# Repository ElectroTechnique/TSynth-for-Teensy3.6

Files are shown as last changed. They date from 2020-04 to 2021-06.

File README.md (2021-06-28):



# Teensy 3.6 based synthesizer using PJRC Audio Board and Audio Lib

# Superceded by Teensy 4.1 version

Website: [electrotechnique.cc](https://electrotechnique.cc)

The pcb and front panel to build TSynth will be available around May 2020 from [Tindie](https://www.tindie.com/products/electrotechnique/tsynth-teensy-based-diy-programmable-poly-synth/) with SMD 4067 multiplexers, 6N138 opto-isolator, capacitors and resistors fitted. The entire cost of parts to build TSynth will be around $99 if you buy components from the cheaper suppliers and the build time around two hours to solder. Plans for a 3D printed/laser cut enclosure will be available.
Questions: info@electrotechnique.cc

# Instructions

The source code requires Teensyduino from [PJRC](https://pjrc.com) to compile. You also need CircularBuffer from Agileware and Adafruit_GFX, which are available in the Arduino Library Manager. The latest TeensyDuino v1.54beta9+ appears to work fine now.

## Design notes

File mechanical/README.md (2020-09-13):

- Electrical schematic
- 3D models
- Laser cutter plans
- Mechanical plans
- BOM Excel file for ordering from Mouser

- T4.1 to T3.6 Adapter Board KiCAD files and gerbers for JLCPCB. Use to fit a T4.1 on the Rev 1.1 T3.6-based board. You do not need this unless you want to covert your Rev1.1 PCB to use a T4.1 and use the firmware.

Fusion 360 models. These have internal dimensions for slots that are slightly bigger, to account for shrinkage of PLA plastic:
- [End Cheeks](https://a360.co/3azEESA)
- [Side Panel Column](https://a360.co/34T8akU)

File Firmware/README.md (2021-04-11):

This is the current firmware for TSynth - use the latest, earlier ones will be left here. It is a hex file that is flashed to Teensy using [Teensy Loader from PJRC](https://www.pjrc.com/teensy/loader.html) You will probably need to press the button on a the Teensy for the firmware to flash.

- V1.29 - Stereo chorus improvement.

- V1.28 - Mod wheel level adds to osc LFO level.

- V1.27 - The volume control affects digital and analogue audio together. This can be loud on the headphone socket.

- V1.26 - Improve ADC reads to decrease noise and increase sensitivity to pot changes. Increase AudioMemory to 48.

- V1.24 - Improved filter response at higher frequencies.

- V1.23 - Added MIDI Out - panel controls will send MIDI CC data over a channel set in Settings through USB Host and Client MIDI ports. Added VU Meter that shows peak amplitude on display (enabled in Settings.) Not a true VU meter, however.

- V1.22 - Fixed glide behaviour when notes were held.

- V1.21 - Fixed odd glide behaviour. Now glides correctly from previous note.

- V1.20 - Added oscilloscope display option in Settings. This is an 'experimental feature' that needs more work.

- V1.19 - Added 'Pick-up' option which allows certain controls (both front panel and MIDI) to only change the value when the current patch value is 'picked-up'. For example, if Freq Cutoff is set to 312Hz, adjusting Filter Cutoff will pick-up the value when the control is near 312Hz and then change it. This prevents sudden jumps in sound when playing and adjusting. Filter Cuttoff, Resonance, Filter Type, Pitch LFO Amount, Pitch LFO Rate, Filter LFO Amount, Filter LFO Rate, FX Amount and FX Mix have pick-up as these are most likely to be adjusted during performance. This feature is somewhat experimental but good enough to include. An indicator, 'PK' shows when pick-up is enabled on the parameter value page of the display. Also added 'Bass Enhance' to the Settings menu. This enhances bass frequencies using the SGTL5000 audio codec chip (not the Teensy) and will only be heard through the headphone jack not USB digital audio.

- V1.17 - Velocity sensitivity added. There are four velocity curves (see [electrotechnique.cc](https://electrotechnique.cc) post about this) that change the volume level with the velocity value. Also a minor fix to PWM source changing that failed to switch the filter envelope on when coming from fixed PW.

- V1.16 - Envelopes closed when a patch changes or the Panic button is pressed, to prevent next patch sounding.

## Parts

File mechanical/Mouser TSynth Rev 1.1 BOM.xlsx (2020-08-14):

Mouser # | Mfr. # | Manufacturer | Description | Order Qty. | Datasheet URL | Quoted Part Number | Order Quantity | Order Price | Min\Mult Order Qty
474-DEV-14057 | DEV-14057 | SparkFun Electronics | Development Boards & Kits - ARM Teensy 3.6 | 1 |  | 474-DEV-14057 | 1 | $32.50 | 1\1
474-DEV-15421 | DEV-15421 | SparkFun Electronics | Audio IC Development Tools Teensy Audio Adaptor Board | 1 |  | 474-DEV-15421 | 1 | $17.50 | 1\1
652-PTV09A-4025UB103 | PTV09A-4025U-B103 | Bourns | Potentiometers 10K LINEAR 20% | 33 | https://www.mouser.com/datasheet/2/54/ptv09-777818.pdf | 652-PTV09A-4025UB103 | 33 | $0.672 | 1\1
653-B3F-4055 | B3F-4055 | Omron | Tactile Switches 12x12mm Std Ht .3 High-force 260g | 7 | https://www.mouser.com/datasheet/2/307/en-b3f-13826.pdf | 653-B3F-4055 | 7 | $0.44 | 1\1
642-AKTS22K | AKTSC22K | Apem | Switch Bezels / Switch Caps ROUND BLACK CAP | 7 | https://www.mouser.com/catalog/additional/Apem_6420_RoHS_Certificate.pdf | 642-AKTS22K | 7 | $0.23 | 1\1
859-LTL-4251NLC | LTL-4251NLC | Lite-On | Standard LEDs - Through Hole Yellow | 4 | https://www.mouser.com/catalog/additional/Lite_On_5938_RoHS_Certificate.pdf | 859-LTL-4251NLC | 4 | $0.14 | 1\1
652-PEC11R-4215K-S24 | PEC11R-4215K-S0024 | Bourns | Encoders 15mm SHAFT w/SWITCH | 1 | https://www.mouser.com/datasheet/2/54/PEC11R-777457.pdf | 652-PEC11R-4215K-S24 | 1 | $1.63 | 1\1
530-SS-52100-001 | SS-52100-001 | Bel | USB Connectors USB 2.0 R Angle Recpt Type A solder | 1 | https://belfuse.com/resources/datasheets/stewartconnector/ds-stw-usb-2.0-and-3.0-connectors.pdf | 530-SS-52100-001 | 1 | $0.43 | 1\1
530-SS-52300-001 | SS-52300-001 | Bel | USB Connectors USB 2.0 RA Receptacle Type B | 1 | https://belfuse.com/resources/datasheets/stewartconnector/ds-stw-usb-2.0-type-b-connectors.pdf | 530-SS-52300-001 | 1 | $0.98 | 1\1
161-3507-E | 161-3507-E | Kobiconn | Phone Connectors PHONE 3.5MM STEREO | 1 | https://www.mouser.com/datasheet/2/209/KC-301159-1171664.pdf | 161-3507-E | 1 | $0.96 | 1\1
806-KCDX-5S-N | KCDX-5S-N | Kycon | Circular DIN Connectors 5P R/A PCB NON SHLD 10mm CIRC DIN RECPT | 1 | https://www.mouser.com/datasheet/2/222/KCDX-334811.pdf | 806-KCDX-5S-N | 1 | $0.86 | 1\1

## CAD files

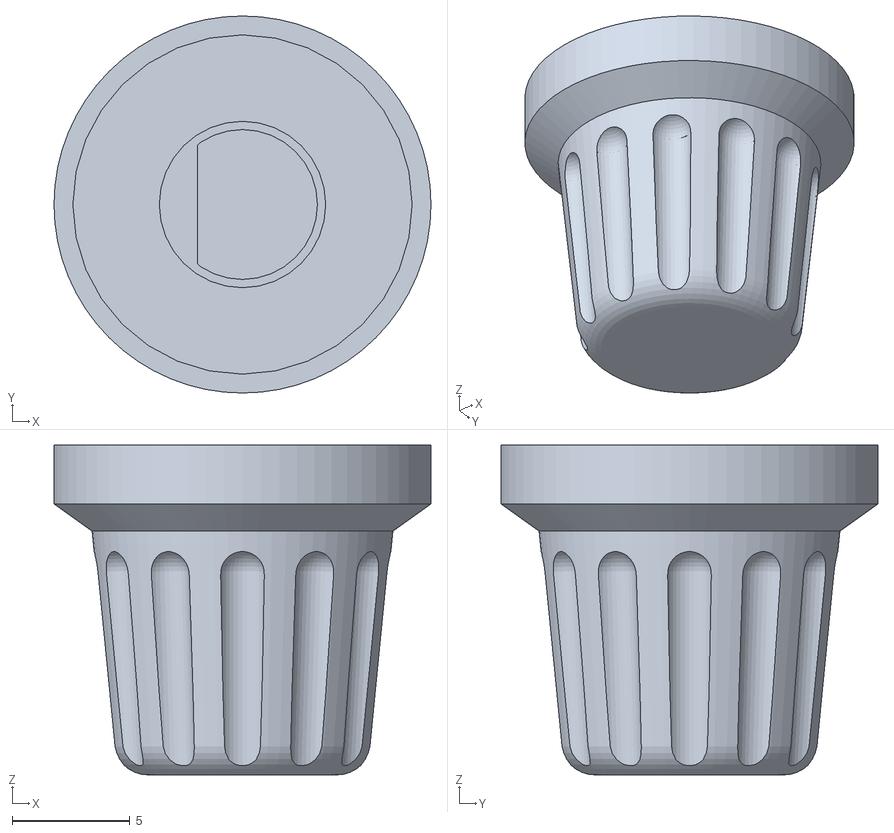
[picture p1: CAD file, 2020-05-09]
mechanical/EncoderKnobEC12.stl
16.0 x 16.0 x 14.0

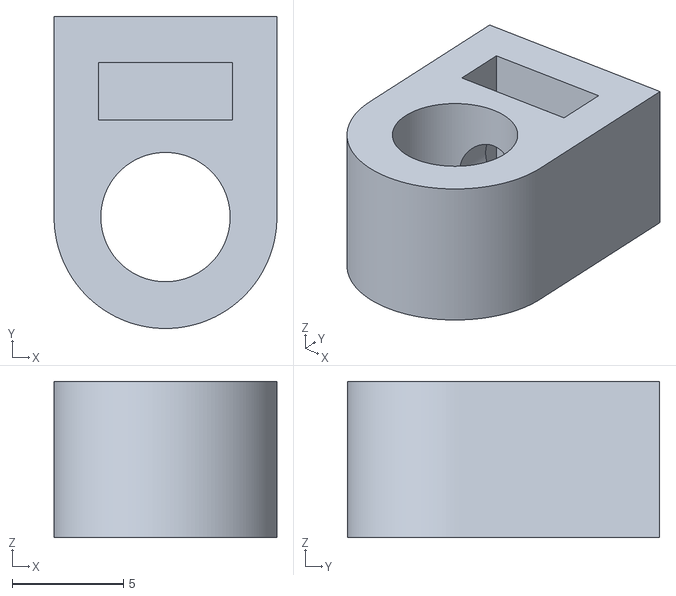
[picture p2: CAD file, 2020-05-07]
mechanical/Side_Panel_Column.stl
10.0 x 14.0 x 7.00

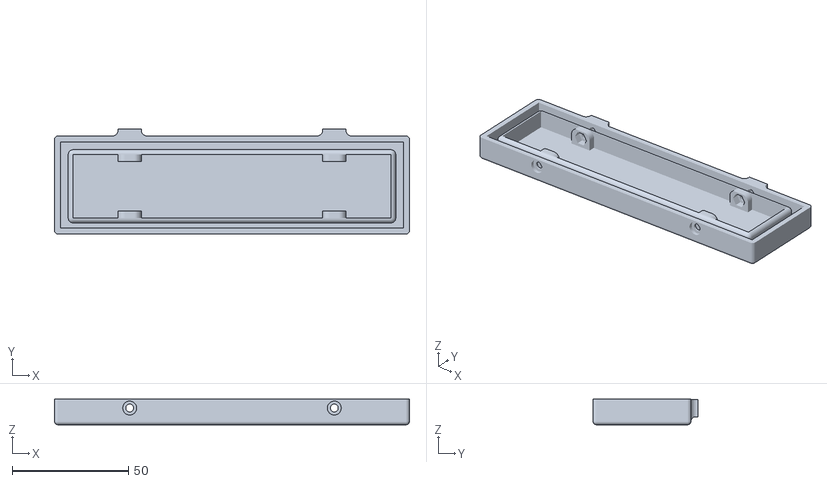
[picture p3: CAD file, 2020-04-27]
mechanical/EndCheek.stl
152.5 x 45.1 x 11.0

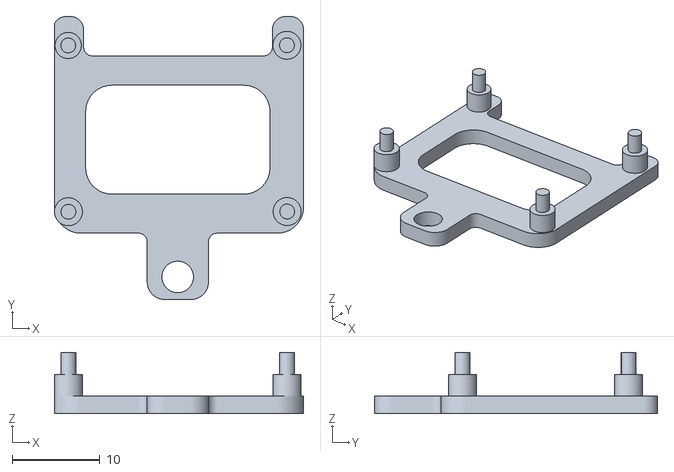
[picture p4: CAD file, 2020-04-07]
mechanical/0_96_Display_Standoff.stl
28.5 x 32.3 x 7.00

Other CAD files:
mechanical/EncoderKnobEC12.scad

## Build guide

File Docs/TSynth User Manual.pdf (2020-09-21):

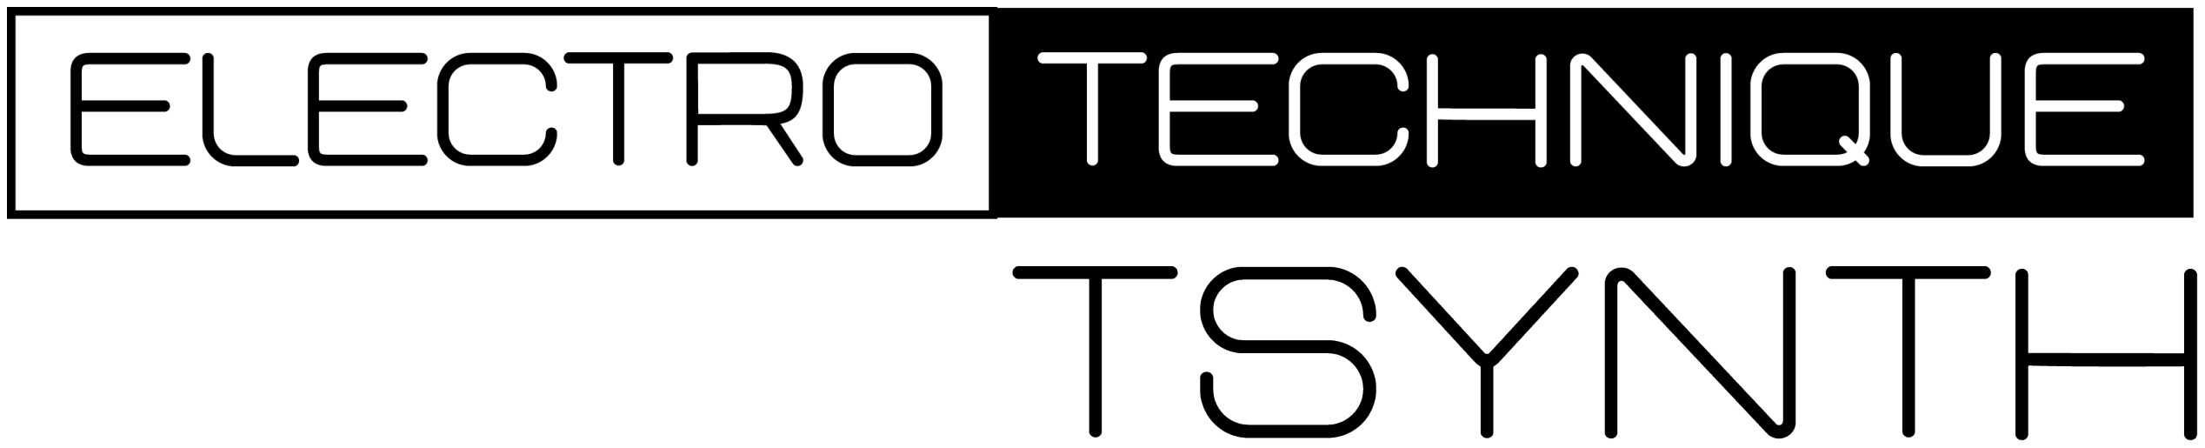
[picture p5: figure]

# User Manual

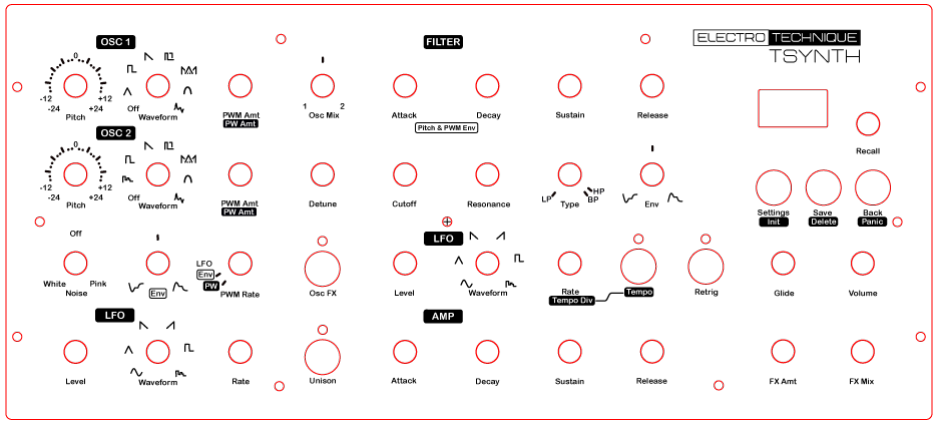
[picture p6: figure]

TSynth is a programmable polyphonic synthesizer based on the Teensy microcontroller board. The front panel is divided into distinct regions that should be familiar to anyone who has used an analogue or analogue-like synthesizer.

### Oscillators

Both oscillators are identical except for the first and last waveforms. Oscillator 1 has triangle and oscillator 2 has sample & hold (which is an audible random value pulse wave.) Octave sets the pitch of the oscillator relative to the other. It ranges from -24 semitone to +24 semitones with values of -24 and -12 to +12 in semitone intervals, then +24. The waveforms available are the usual triangle, square, sawtooth, the already mentioned sample & hold, plus variable pulse, variable triangle (sawtooth to triangle to ramp waveforms), rectified sine (parabola) and harmonic (these differ on both oscillators for variety).
Pulse width may be set to a fixed value or modulated using the filter envelope or a dedicated LFO - PWM Rate (see section on PWM Controls.)
The volumes of each oscillator may be adjusted using Osc Mix, which mixes between both oscillators on full (middle) or decreasing one down to zero while the other is full. To turn an oscillator off, the waveform can be set to Off.
Detune detunes oscillator 2 relative to oscillator 1 and is useful for giving a thicker, chorus-like effect. This also works with Unison, which will detune all the voices relative to the others, up to the maximum set by Detune.
Noise will allow White or Pink noise to be introduced. The centre setting is Off and adjusting each side will increase the volume of either White or Pink.

Teensy 3.6
September 2020

Env is a pitch modulation applied by the filter envelope. Centre setting is none and this may be adjusted to increase a negative or postive envelope. Negative (anticlockwise) goes down then up. Positive (clockwise) goes up then down.
The oscillators have their own dedicated LFO. This has a Level control for the amount. A Waveform choice and a Rate (speed) setting. The Waveforms are sine, triangle, sawtooth, ramp (or reverse sawtooth), square and sample & hold.
Osc FX applies a Korg MS20 style, XOR type ‘ring modulation’ effect to the oscillators. This introduces harmonics to the sound and may not work with certain combinations of waveforms such as two pulse types. This could be expanded in future to allow other types of effect.
Unison sounds all the oscillators together when a note is played and sets the synth monophonic. As mentioned, Detune will set all the oscillators slightly detuned from each other up to the maximum set by the Detune control.

### PWM Controls

Both oscillators feature variable pulse and variable triangle waveforms that can be manually adjusted or modulated by the filter envelope or a dedicated LFO.
Fixed Pulse Width / Triangle shape
Set the PWM Rate control to zero where it’s marked PW. The two controls above - PW Amt will set the pulse width / triangle shape. The central middle setting corresponds to a square wave (50% duty cycle) or a triangle waveform depending on the oscillator waveform.
Pulse Width / Triangle shape modulation by filter envelope
Set the PWM Rate control to where it’s marked Env. The two controls above - PWM Amt will set the amount of modulation pulse width / triangle shape receive from the filter envelope.
Pulse Width / Triangle shape modulation by LFO
Set the PWM Rate control to LFO and above. The two controls above - PWM Amt will set the amount of modulation the pulse width / triangle shape receive from the a dedicated LFO. PWM Rate will adjust the rate (speed) of this LFO. The LFO waveform is a sine wave.

### Filter

The Filter section features an ADSR envelope with Attack, Decay and Release times from 1ms up to almost 12s, which is also used by the oscillators pitch envelope and by the PWM control, as outlined in the Oscillators section. The envelope modulates the cutoff frequency of the filter and the amount of the effect is by the Env control, which allows a positive (clockwise) or negative (anticlockwise) modulation of the cutoff.
The cutoff frequency is controlled by the Cutoff control, with resonance level set by the Resonance control. The Type control will vary the filter type between low pass (LP) through to high pass (HP) acting as a notch filter, to band pass (BP). This is known as a state variable filter and has a 12dB per octave cutoff response. Resonance may produce distortion when set to full with the cutoff at the resonant frequencies of particular waveforms.
There is a dedicated LFO for the filter with a Level control, a selection of Waveforms and a Rate (speed) control. Setting the Tempo switch to on, makes the LFO sync with incoming MIDI clock signals from a sequencer (like Ableton Live, Logic Pro etc) This also allows the Rate control to set the tempo divisions for a particular tempo. The Tempo Div control will allow the LFO to sync to a frequency that is a division of a bar 1/16, 3/32, 1/8, 3/16, 1/4 .... for a particular tempo, in beats per minute (bpm).
Retrig will retrigger the LFO to start from the same point in the waveform every time a new note is pressed regardless of whether other notes are still held. This can be useful if you want to play a series of notes and have the filter modulate each note in the same way.

### Amplifier

This is a standard ADSR envelope with Attack, Decay and Release times from 1ms up to almost 12s.

### Saving and Naming Patches

Back button will cancel and move back to previous screen. If you make a mistake naming patches, press back button.

### Save a new patch

Save Recall Turn the Recall encoder to select
letters and numbers. Press Recall to select each character and move to the next one to select. Press to select final character.
- Save

### Overwriting an existing patch

Save Turn the Recall encoder to select the patch to overwrite.

- Save

### Renaming an existing patch

Save Turn the Recall
encoder to select the patch
to rename and
press Recall.
- Turn the Recall encoder to select letters and numbers. Press Recall to select each character and move to the
next one to select. Press to select final character.
- Save

### Settings

Pressing Settings allows access to a number of patch and global level settings for TSynth. These are: MIDI Ch. - The MIDI channel TSynth will accept incoming MIDI data on, including All (Omni on). This is global.
Key Tracking - This modulates the filter cutoff frequency as you go up the keyboard to higher notes. The idea is that the cutoff increases to allow higher frequencies to sound clearer. It can be set to None (cutoff doesn’t change) Half (some effect) and Full (full effect). This is saved with the patch.
Velocity Sens - This sets the velocity sensitivity of the amplifier and has four curves:
1 - Linear, velocity value corresponds directly to the loudness. 2 - Curve to maximum loudness.
3 - Curve to maximum loudness at 70 and then flatten.

4 - Curve up to maximum loudness.

Choose an appropriate curve for the keyboard response. This is saved with the patch.
Pitch Bend - this sets the pitch bend range in semitones. This is global.
MW Depth - this sets the modulation wheel maximum depth. This is like the level control in the oscillator LFO section but allows lower levels of modulation (vibrato in this case) to be applied. This is global.
MIDI Out Ch. - The channel MIDI out will transmit on. Can be switched off. Only works over USB host and client and is useful for recording parameter changes while recording a sequence. This is global.
Encoder - Choose Type 1 or Type 2 depending on how your encoder produces pulses when turning. If your encoder decrements when turning clockwise, change the type here. This is global. Pick-up - An experimental feature that only allows a panel control and the corresponding MIDI CC control, to start changing the parameter value when it matches the current patch value. This is to prevent jumps when the control suddenly changes the parameter value. Turn the control slowly and smoothly, and the control will pick-up the current value when it gets to it and change it. An icon of a knob appears on the display when changing parameters, when this is on. This is global.
Bass Enh. - This enhances the bass frequencies using the SGTL5000 codec chip on the audio board and doesn’t involve the Teensy. This will only affect audio from the headphone socket. This is global.
Oscilloscope - An experimental feature that shows what the waveforms look like. This is taken just before the stereo chorus effect. This is global.
VU Meter - This is a linear meter that shows the amplitude of the audio signal - not really VU standard. This is global.
The Settings menu allows scope for expansion; for example, velocity sensitivity could be set for the modulation of the filter cutoff frequency. You could set different types of filter, user waveforms, effects...

### Initialisation

Pressing and holding the Settings button for one second invokes Init, which will re-read all the panel controls and set TSynth to the current panel settings.

### Other Specifications

Power - 5V 180mA from USB
Digital Audio - 16 bit, 44.117Hz (for Teensy 3.6) - headphone jack and audio interface recommended for recording.

### Known Issues

Occasional digital noises from audio over USB, possibly attributable to the 44117Hz sample rate T3.6 uses. T4 uses 44100Hz and will probably be better. Audio from Audio Board is fine and is recommended for recording purposes.
Plugging in a MIDI controller may alter current patch settings. Arturia Minilab for example, sends its current panel control settings when plugged in, causing MIDI CC messages to be received by TSynth, altering settings.
Low cost (sub $10) USB to MIDI converters can have problems handling clock signals and Sys-Ex, which get mixed up with note on/off and CC messages. Use quality converters made by a known brand name.

There is a significant latency (delay) between TSynth receiving a MIDI note and hearing it on a computer via USB audio - about 100ms. For recording, use the headphone output and send through a quality audio interface featuring low latency ASIO drivers.

### Troubleshooting

No sound
- Check Waveforms are not set to off and volume is mid way.
- Check filter cutoff and filter type will allow sound through.
- Pulse Width of Pulse waveforms will be quiet if set to maximum (very narrow!)
- If using digital audio via USB, check your computer. Windows sometimes doesn’t pass the audio through - Go into the Control Panel, Manage Audio Devices and the Recording tab. Double-click the digital audio device and go into the Listen tab and set the Listen to this device to on - you may find it’s already on and you have to toggle it off and on so it works again.
Pressing Init to set TSynth to the panel control current settings and with the controls set to make sound, will show if there is a problem.

Digital noises
This may happen occasionally when using the USB digital audio. The analogue audio is fine.
Not all the waveforms are anti-aliased / band limited and noise will be noticeable with higher frequencies and particularly with the variable pulse waveform. This is another area for improvement within the Audio Library. The chorus / ensemble effect may also introduce some noise.
Humming Noises
This could be attributable to ground or mains noise through the USB port if connected to a pc or an external amplifier and needs action by you see what configuration works. TSynth can be powered from a USB powerbank and played by a small MIDI controller without an attachment to the mains or a pc, this would show if noise is from the mains or possibly your computer.

SD Card problems
Use a low value (1GB is more than enough!) SD card. It doesn’t need to be particularly fast and cheaper, older cards are fine. Ensure that the card is formatted as FAT16 before using it and the SDFormatter application from the SD Association is recommended:
www.sdcard.org/downloads/formatter/
Other problems
If there are intermittant problems, check the hardware. Are there dry solder joints, is the Teensy properly seated in the header socket if you used one, are the potentiometers smooth. TSynth is a DIY project and it is up to the individual to build it properly.

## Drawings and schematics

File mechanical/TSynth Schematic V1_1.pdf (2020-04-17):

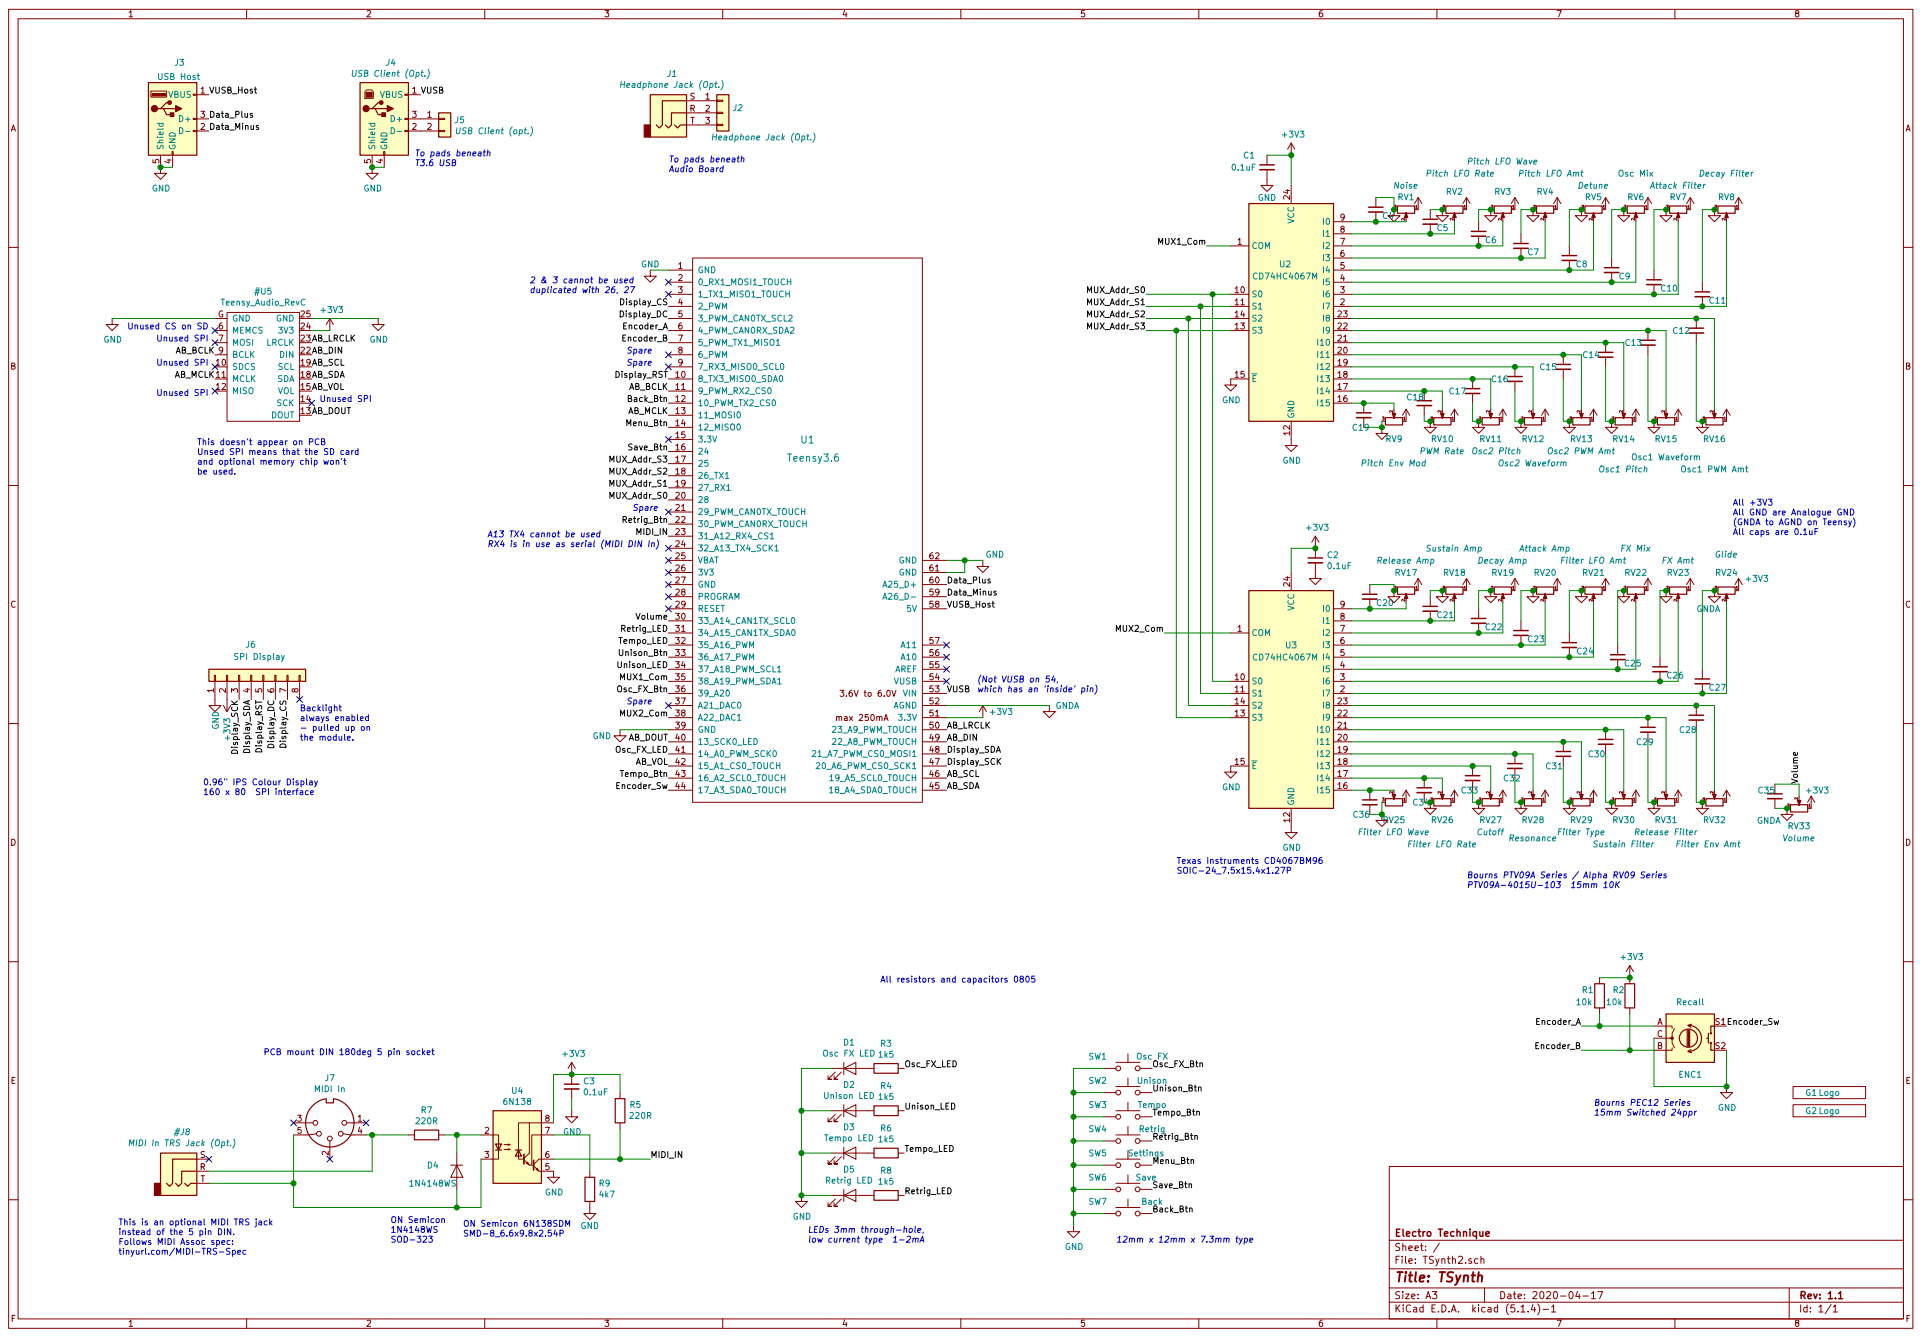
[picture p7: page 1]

Unused SPI Unused SPI Unused CS on SD

3RV25 Filter LFO Wave D5 Retrig LED

Bourns PTV09A Series / Alpha RV09 Series PTV09A-4015U-103 15mm 10K

All resistors and capacitors 0805

PCB mount DIN 180deg 5 pin socket This is an optional MIDI TRS jack

instead of the 5 pin DIN. Follows MIDI Assoc spec:

File: TSynth2.sch Sheet: / Electro Technique

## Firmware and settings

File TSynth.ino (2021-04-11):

/*
   MIT License

  Copyright (c) 2020-21 ElectroTechnique

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
  ElectroTechnique TSynth - Firmware Rev 1.29

  Includes code by:
    Dave Benn - Handling MUXs, a few other bits and original inspiration  https://www.notesandvolts.com/2019/01/teensy-synth-part-10-hardware.html
    Alexander Davis / Vince R. Pearson - Stereo ensemble chorus effect https://github.com/quarterturn/teensy3-ensemble-chorus
    Gustavo Silveira - Band limited wavetables https://forum.pjrc.com/threads/41905-Band-limited-Sawtooth-wavetable-C-generator-for-quot-Arbitrary-Waveform-quot-(and-its-use)
    Holger Wirtz - Modified library integration and special thanks https://www.parasitstudio.de/

  Arduino IDE
  Tools Settings:
  Board: "Teensy3.6"
  USB Type: "Serial + MIDI + Audio"
  CPU Speed: "180MHz"
  Optimize: "Faster"

  +++ Compiling with overclocking can lead to problems, test carefully +++
  Performance Tests   CPU  Mem
  180Mhz Faster       81.6 46
  180Mhz Fastest      77.8 46
  180Mhz Fastest+PC   79.0 46
  180Mhz Fastest+LTO  76.7 46
  240MHz Fastest+LTO  55.9 46

  Additional libraries:
    Agileware CircularBuffer, Adafruit_GFX (available in Arduino libraries manager)
*/

#include "Audio.h" //Using local version to override Teensyduino version
#include <Wire.h>
#include <SPI.h>
#include <SD.h>
#include <MIDI.h>
#include <USBHost_t36.h>
#include "MidiCC.h"
#include "AudioPatching.h"
#include "Constants.h"
#include "Parameters.h"
#include "PatchMgr.h"
#include "HWControls.h"
#include "EepromMgr.h"
#include "sawtoothWave.h"
#include "squareWave.h"
#include "Velocity.h"

#define PARAMETER 0 //The main page for displaying the current patch and control (parameter) changes
#define RECALL 1 //Patches list
#define SAVE 2 //Save patch page
#define REINITIALISE 3 // Reinitialise message
#define PATCH 4 // Show current patch bypassing PARAMETER
#define PATCHNAMING 5 // Patch naming page
#define DELETE 6 //Delete patch page
#define DELETEMSG 7 //Delete patch message page
#define SETTINGS 8 //Settings page
#define SETTINGSVALUE 9 //Settings page

unsigned int state = PARAMETER;

#define WAVEFORM_SAWTOOTH_WT 101
#define WAVEFORM_SQUARE_WT 102
#define WAVEFORM_PARABOLIC 103
#define WAVEFORM_HARMONIC 104

struct VoiceAndNote {
  int note;
  long timeOn;
  boolean voiceOn;
};

struct VoiceAndNote voices[NO_OF_VOICES] = {
  { -1, 0, false},
  { -1, 0, false},
  { -1, 0, false},
  { -1, 0, false},
  { -1, 0, false},
  { -1, 0, false}
};

#include "ST7735Display.h"
#include "Settings.h"

boolean cardStatus = false;
boolean firstPatchLoaded = false;

//USB HOST MIDI Class Compliant
USBHost myusb;
USBHub hub1(myusb);
USBHub hub2(myusb);
MIDIDevice midi1(myusb);

//MIDI 5 Pin DIN
MIDI_CREATE_INSTANCE(HardwareSerial, Serial4, MIDI); //RX - Pin 31

int prevNote = 48;//This is for glide to use previous note to glide from
float previousMillis = millis(); //For MIDI Clk Sync

int count = 0;//For MIDI Clk Sync
int patchNo = 1;//Current patch no
int voiceToReturn = -1; //Initialise
long earliestTime = millis(); //For voice allocation - initialise to now

void setup()
{
  setupDisplay();
  setUpSettings();
  setupHardware();

  AudioMemory(48);
  sgtl5000_1.enable();
  sgtl5000_1.dacVolumeRamp();
  sgtl5000_1.volume(SGTL_MAXVOLUME); //Headphones
  sgtl5000_1.audioPostProcessorEnable();
  sgtl5000_1.enhanceBass(0.85, 0.87, 0, 4);//Normal level, bass level, HPF bypass (1 - on), bass cutoff freq
  sgtl5000_1.enhanceBassDisable();//Turned on from EEPROM

  cardStatus = SD.begin(BUILTIN_SDCARD);
  if (cardStatus)
  {
    Serial.println("SD card is connected");
    //Get patch numbers and names from SD card
    loadPatches();
    if (patches.size() == 0)
    {
      //save an initialised patch to SD card
      savePatch("1", INITPATCH);
      loadPatches();
    }
  }
  else
  {
    Serial.println("SD card is not connected or unusable");
    reinitialiseToPanel();
    showPatchPage("No SD", "conn'd / usable");
  }

  //Read MIDI Channel from EEPROM
  midiChannel = getMIDIChannel();
  Serial.println("MIDI Ch:" + String(midiChannel) + " (0 is Omni On)");

  //USB HOST MIDI Class Compliant
  delay(200); //Wait to turn on USB Host
  myusb.begin();
  midi1.setHandleControlChange(myControlChange);
  midi1.setHandleNoteOff(myNoteOff);
  midi1.setHandleNoteOn(myNoteOn);
  midi1.setHandlePitchChange(myPitchBend);
  midi1.setHandleProgramChange(myProgramChange);
  midi1.setHandleClock(myMIDIClock);
  midi1.setHandleStart(myMIDIClockStart);
  midi1.setHandleStop(myMIDIClockStop);
  Serial.println("USB HOST MIDI Class Compliant Listening");

  //USB Client MIDI
  usbMIDI.setHandleControlChange(myControlChange);
  usbMIDI.setHandleNoteOff(myNoteOff);
  usbMIDI.setHandleNoteOn(myNoteOn);
  usbMIDI.setHandlePitchChange(myPitchBend);
  usbMIDI.setHandleProgramChange(myProgramChange);
  usbMIDI.setHandleClock(myMIDIClock);
  usbMIDI.setHandleStart(myMIDIClockStart);
  usbMIDI.setHandleStop(myMIDIClockStop);
  Serial.println("USB Client MIDI Listening");

  //MIDI 5 Pin DIN
  MIDI.begin();
  MIDI.setHandleNoteOn(myNoteOn);
  MIDI.setHandleNoteOff(myNoteOff);
  MIDI.setHandlePitchBend(myPitchBend);
  MIDI.setHandleControlChange(myControlChange);
  MIDI.setHandleProgramChange(myProgramChange);
  MIDI.setHandleClock(myMIDIClock);
  MIDI.setHandleStart(myMIDIClockStart);
  MIDI.setHandleStop(myMIDIClockStop);
  Serial.println("MIDI In DIN Listening");

  constant1Dc.amplitude(ONE);

  noiseMixer.gain(0, ONE);
  noiseMixer.gain(1, ONE);
  noiseMixer.gain(2, 0);
  noiseMixer.gain(3, 0);

  voiceMixer1.gain(0, VOICEMIXERLEVEL);
  voiceMixer1.gain(1, VOICEMIXERLEVEL);
  voiceMixer1.gain(2, VOICEMIXERLEVEL);
  voiceMixer1.gain(3, 0);

  voiceMixer2.gain(0, VOICEMIXERLEVEL);
  voiceMixer2.gain(1, VOICEMIXERLEVEL);
  voiceMixer2.gain(2, VOICEMIXERLEVEL);
  voiceMixer2.gain(3, 0);

  voiceMixerM.gain(0, 0.5f);
  voiceMixerM.gain(1, 0.5f);
  voiceMixerM.gain(2, 0);
  voiceMixerM.gain(3, 0);

  pwmLfo.amplitude(ONE);
  pwmLfo.begin(PWMWAVEFORM);

  waveformMod1a.frequency(440);
  waveformMod1a.amplitude(ONE);
  waveformMod1a.frequencyModulation(PITCHLFOOCTAVERANGE);
  waveformMod1a.begin(oscWaveformA);

  waveformMod1b.frequency(440);
  waveformMod1b.amplitude(ONE);
  waveformMod1b.frequencyModulation(PITCHLFOOCTAVERANGE);
  waveformMod1b.begin(oscWaveformB);

  waveformMod2a.frequency(440);
  waveformMod2a.amplitude(ONE);
  waveformMod2a.frequencyModulation(PITCHLFOOCTAVERANGE);
  waveformMod2a.begin(oscWaveformA);

  waveformMod2b.frequency(440);
  waveformMod2b.amplitude(ONE);
  waveformMod2b.frequencyModulation(PITCHLFOOCTAVERANGE);
  waveformMod2b.begin(oscWaveformB);

  waveformMod3a.frequency(440);
  waveformMod3a.amplitude(ONE);
  waveformMod3a.frequencyModulation(PITCHLFOOCTAVERANGE);
  waveformMod3a.begin(oscWaveformA);

  waveformMod3b.frequency(440);
  waveformMod3b.amplitude(ONE);
  waveformMod3b.frequencyModulation(PITCHLFOOCTAVERANGE);
  waveformMod3b.begin(oscWaveformB);

  waveformMod4a.frequency(440);
  waveformMod4a.amplitude(ONE);
  waveformMod4a.frequencyModulation(PITCHLFOOCTAVERANGE);
  waveformMod4a.begin(oscWaveformA);

  waveformMod4b.frequency(440);
  waveformMod4b.amplitude(ONE);
  waveformMod4b.frequencyModulation(PITCHLFOOCTAVERANGE);
  waveformMod4b.begin(oscWaveformB);

  waveformMod5a.frequency(440);
  waveformMod5a.amplitude(ONE);
  waveformMod5a.frequencyModulation(PITCHLFOOCTAVERANGE);
  waveformMod5a.begin(oscWaveformA);

  waveformMod5b.frequency(440);
  waveformMod5b.amplitude(ONE);
  waveformMod5b.frequencyModulation(PITCHLFOOCTAVERANGE);
  waveformMod5b.begin(oscWaveformB);

  waveformMod6a.frequency(440);
  waveformMod6a.amplitude(ONE);
  waveformMod6a.frequencyModulation(PITCHLFOOCTAVERANGE);
  waveformMod6a.begin(oscWaveformA);

  waveformMod6b.frequency(440);
  waveformMod6b.amplitude(ONE);
  waveformMod6b.frequencyModulation(PITCHLFOOCTAVERANGE);
  waveformMod6b.begin(oscWaveformB);

  //Arbitary waveform needs initialising to something
  loadArbWaveformA(PARABOLIC_WAVE);
  loadArbWaveformB(PARABOLIC_WAVE);

  waveformMixer1.gain(2, ONE); //Noise
  waveformMixer1.gain(3, 0);           //Osc FX
  waveformMixer2.gain(2, ONE); //Noise
  waveformMixer2.gain(3, 0);           //Osc FX
  waveformMixer3.gain(2, ONE); //Noise
  waveformMixer3.gain(3, 0);           //Osc FX
  waveformMixer4.gain(2, ONE); //Noise
  waveformMixer4.gain(3, 0);           //Osc FX
  waveformMixer5.gain(2, ONE); //Noise
  waveformMixer5.gain(3, 0);           //Osc FX
  waveformMixer6.gain(2, ONE); //Noise
  waveformMixer6.gain(3, 0);           //Osc FX

  filterModMixer1.gain(1, ONE); //LFO
  filterModMixer1.gain(3, 0);           //Not used
  filterModMixer2.gain(1, ONE); //LFO
  filterModMixer2.gain(3, 0);           //Not used
  filterModMixer3.gain(1, ONE); //LFO
  filterModMixer3.gain(3, 0);           //Not used
  filterModMixer4.gain(1, ONE); //LFO
  filterModMixer4.gain(3, 0);           //Not used
  filterModMixer5.gain(1, ONE); //LFO
  filterModMixer5.gain(3, 0);           //Not used
  filterModMixer6.gain(1, ONE); //LFO
  filterModMixer6.gain(3, 0);           //Not used

  filterMixer1.gain(3, 0); //Not used
  filterMixer2.gain(3, 0); //Not used
  filterMixer3.gain(3, 0); //Not used
  filterMixer4.gain(3, 0); //Not used
  filterMixer5.gain(3, 0); //Not used
  filterMixer6.gain(3, 0); //Not used

  //This removes dc offset (mostly from unison pulse waves) before the ensemble effect
  dcOffsetFilter.octaveControl(1.0);
  dcOffsetFilter.frequency(12.0);//Lower values will give clicks on note on/off

  ensemble.lfoRate(fxAmt);

  effectMixerL.gain(2, 0);
  effectMixerL.gain(3, 0);
  effectMixerR.gain(2, 0);
  effectMixerR.gain(3, 0);

  volumePrevious = RE_READ; //Force volume control to be read and set to current

  //Read Pitch Bend Range from EEPROM
  pitchBendRange = getPitchBendRange();

  //Read Mod Wheel Depth from EEPROM
  modWheelDepth = getModWheelDepth();

  //Read MIDI Out Channel from EEPROM
  midiOutCh = getMIDIOutCh();

  //Read Encoder Direction from EEPROM
  encCW = getEncoderDir();

  //Read bass enhance enable from EEPROM
  if (getBassEnhanceEnable()) sgtl5000_1.enhanceBassEnable();

  //Read Pick-up enable from EEPROM - experimental feature
  pickUp = getPickupEnable();

  //Read oscilloscope enable from EEPROM
  enableScope(getScopeEnable());

  //Read VU enable from EEPROM
  vuMeter = getVUEnable();
}

void myNoteOn(byte channel, byte note, byte velocity)
{
  //Check for out of range notes
  if (note + oscPitchA < 0 || note + oscPitchA > 127 || note + oscPitchB < 0 || note + oscPitchB > 127)
    return;

  if (oscLfoRetrig == 1)
  {
    pitchLfo.sync();
  }
  if (filterLfoRetrig == 1)
  {
    filterLfo.sync();
  }

  if (unison == 0)
  {
    switch (getVoiceNo(-1))
    {
      case 1:
        keytracking1.amplitude(note * DIV127 * keytrackingAmount);
        voices[0].note = note;
        voices[0].timeOn = millis();
        voiceMixer1.gain(0, VELOCITY[velocitySens][velocity] * VOICEMIXERLEVEL);
        updateVoice1();
        filterEnvelope1.noteOn();
        ampEnvelope1.noteOn();
        voices[0].voiceOn = true;
        if (glideSpeed > 0 && note != prevNote)
        {
          glide1.amplitude((prevNote - note) * DIV24);   //Set glide to previous note frequency (limited to 1 octave max)
          glide1.amplitude(0, glideSpeed * GLIDEFACTOR); //Glide to current note
        }
        prevNote = note;
        break;
      case 2:
        keytracking2.amplitude(note * DIV127 * keytrackingAmount);
        voices[1].note = note;
        voices[1].timeOn = millis();
        voiceMixer1.gain(1, VELOCITY[velocitySens][velocity] * VOICEMIXERLEVEL);
        updateVoice2();
        filterEnvelope2.noteOn();
        ampEnvelope2.noteOn();
        voices[1].voiceOn = true;
        if (glideSpeed > 0 && note != prevNote)
        {
          glide2.amplitude((prevNote - note) * DIV24);   //Set glide to previous note frequency (limited to 1 octave max)
          glide2.amplitude(0, glideSpeed * GLIDEFACTOR); //Glide to current note
        }
        prevNote = note;
        break;
      case 3:
        keytracking3.amplitude(note * DIV127 * keytrackingAmount);
        voices[2].note = note;
        voices[2].timeOn = millis();
        voiceMixer1.gain(2, VELOCITY[velocitySens][velocity] * VOICEMIXERLEVEL);
        updateVoice3();
        filterEnvelope3.noteOn();
        ampEnvelope3.noteOn();
        voices[2].voiceOn = true;
        if (glideSpeed > 0 && note != prevNote)
        {
          glide3.amplitude((prevNote - note) * DIV24);   //Set glide to previous note frequency (limited to 1 octave max)
          glide3.amplitude(0, glideSpeed * GLIDEFACTOR); //Glide to current note
        }
        prevNote = note;
        break;
      case 4:
        keytracking4.amplitude(note * DIV127 * keytrackingAmount);
        voices[3].note = note;
        voices[3].timeOn = millis();
        voiceMixer2.gain(0, VELOCITY[velocitySens][velocity] * VOICEMIXERLEVEL);
        updateVoice4();
        filterEnvelope4.noteOn();
        ampEnvelope4.noteOn();
        voices[3].voiceOn = true;
        if (glideSpeed > 0 && note != prevNote)
        {
          glide4.amplitude((prevNote - note) * DIV24);   //Set glide to previous note frequency (limited to 1 octave max)
          glide4.amplitude(0, glideSpeed * GLIDEFACTOR); //Glide to current note
        }
        prevNote = note;
        break;
      case 5:
        keytracking5.amplitude(note * DIV127 * keytrackingAmount);
        voices[4].note = note;
        voices[4].timeOn = millis();
        voiceMixer2.gain(1, VELOCITY[velocitySens][velocity] * VOICEMIXERLEVEL);
        updateVoice5();
        filterEnvelope5.noteOn();
        ampEnvelope5.noteOn();
        voices[4].voiceOn = true;
        if (glideSpeed > 0 && note != prevNote)
        {
          glide5.amplitude((prevNote - note) * DIV24);   //Set glide to previous note frequency (limited to 1 octave max)
          glide5.amplitude(0, glideSpeed * GLIDEFACTOR); //Glide to current note
        }
        prevNote = note;
        break;
      case 6:
        keytracking6.amplitude(note * DIV127 * keytrackingAmount);
        voices[5].note = note;
        voices[5].timeOn = millis();
        voiceMixer2.gain(2, VELOCITY[velocitySens][velocity] * VOICEMIXERLEVEL);
        updateVoice6();
        filterEnvelope6.noteOn();
        ampEnvelope6.noteOn();
        voices[5].voiceOn = true;
        if (glideSpeed > 0 && note != prevNote)
        {
          glide6.amplitude((prevNote - note) * DIV24);   //Set glide to previous note frequency (limited to 1 octave max)
          glide6.amplitude(0, glideSpeed * GLIDEFACTOR); //Glide to current note
        }
        prevNote = note;
        break;
    }
  }
  else
  {
    //UNISON MODE
    keytracking1.amplitude(note * DIV127 * keytrackingAmount);
    keytracking2.amplitude(note * DIV127 * keytrackingAmount);
    keytracking3.amplitude(note * DIV127 * keytrackingAmount);
    keytracking4.amplitude(note * DIV127 * keytrackingAmount);
    keytracking5.amplitude(note * DIV127 * keytrackingAmount);
    keytracking6.amplitude(note * DIV127 * keytrackingAmount);
    voices[0].note = note;
    voices[0].timeOn = millis();
    voiceMixer1.gain(0, VELOCITY[velocitySens][velocity] * UNISONVOICEMIXERLEVEL);
    updateVoice1();
    voices[1].note = note;
    voices[1].timeOn = millis();
    voiceMixer1.gain(1, VELOCITY[velocitySens][velocity] * UNISONVOICEMIXERLEVEL);
    updateVoice2();
    voices[2].note = note;
    voices[2].timeOn = millis();
    voiceMixer1.gain(2, VELOCITY[velocitySens][velocity] * UNISONVOICEMIXERLEVEL);
    updateVoice3();
    voices[3].note = note;
    voices[3].timeOn = millis();
    voiceMixer2.gain(0, VELOCITY[velocitySens][velocity] * UNISONVOICEMIXERLEVEL);
    updateVoice4();
    voices[4].note = note;
    voices[4].timeOn = millis();
    voiceMixer2.gain(1, VELOCITY[velocitySens][velocity] * UNISONVOICEMIXERLEVEL);
    updateVoice5();
    voices[5].note = note;
    voices[5].timeOn = millis();
    voiceMixer2.gain(2, VELOCITY[velocitySens][velocity] * UNISONVOICEMIXERLEVEL);
    updateVoice6();

    filterEnvelope1.noteOn();
    filterEnvelope2.noteOn();
    filterEnvelope3.noteOn();
    filterEnvelope4.noteOn();
    filterEnvelope5.noteOn();
    filterEnvelope6.noteOn();

    ampEnvelope1.noteOn();
    ampEnvelope2.noteOn();
    ampEnvelope3.noteOn();
    ampEnvelope4.noteOn();
    ampEnvelope5.noteOn();
    ampEnvelope6.noteOn();

    voices[0].voiceOn = true;
    voices[1].voiceOn = true;
    voices[2].voiceOn = true;
    voices[3].voiceOn = true;
    voices[4].voiceOn = true;
    voices[5].voiceOn = true;

    if (glideSpeed > 0 && note != prevNote)
    {
      glide1.amplitude((prevNote - note) * DIV24);   //Set glide to previous note frequency (limited to 1 octave max)
      glide1.amplitude(0, glideSpeed * GLIDEFACTOR); //Glide to current note
      glide2.amplitude((prevNote - note) * DIV24);   //Set glide to previous note frequency (limited to 1 octave max)
      glide2.amplitude(0, glideSpeed * GLIDEFACTOR); //Glide to current note
      glide3.amplitude((prevNote - note) * DIV24);   //Set glide to previous note frequency (limited to 1 octave max)
      glide3.amplitude(0, glideSpeed * GLIDEFACTOR); //Glide to current note
      glide4.amplitude((prevNote - note) * DIV24);   //Set glide to previous note frequency (limited to 1 octave max)
      glide4.amplitude(0, glideSpeed * GLIDEFACTOR); //Glide to current note
      glide5.amplitude((prevNote - note) * DIV24);   //Set glide to previous note frequency (limited to 1 octave max)
      glide5.amplitude(0, glideSpeed * GLIDEFACTOR); //Glide to current note
      glide6.amplitude((prevNote - note) * DIV24);   //Set glide to previous note frequency (limited to 1 octave max)
      glide6.amplitude(0, glideSpeed * GLIDEFACTOR); //Glide to current note
    }
    prevNote = note;
  }
}

void myNoteOff(byte channel, byte note, byte velocity)
{
  if (unison == 0)
  {
    switch (getVoiceNo(note))
    {
      case 1:
        filterEnvelope1.noteOff();
        ampEnvelope1.noteOff();
        voices[0].voiceOn = false;
        break;
      case 2:
        filterEnvelope2.noteOff();
        ampEnvelope2.noteOff();
        voices[1].voiceOn = false;
        break;
      case 3:
        filterEnvelope3.noteOff();
        ampEnvelope3.noteOff();
        voices[2].voiceOn = false;
        break;
      case 4:
        filterEnvelope4.noteOff();
        ampEnvelope4.noteOff();
        voices[3].voiceOn = false;
        break;
      case 5:
        filterEnvelope5.noteOff();
        ampEnvelope5.noteOff();
        voices[4].voiceOn = false;
        break;
      case 6:
        filterEnvelope6.noteOff();
        ampEnvelope6.noteOff();
        voices[5].voiceOn = false;
        break;
    }
  }
  else
  {
    //UNISON MODE
    //If statement prevents the previous different note
    //ending the current note when released
    if (voices[0].note == note)allNotesOff();
  }
}

void allNotesOff()
{
  filterEnvelope1.noteOff();
  ampEnvelope1.noteOff();
  filterEnvelope2.noteOff();
  ampEnvelope2.noteOff();
  filterEnvelope3.noteOff();
  ampEnvelope3.noteOff();
  filterEnvelope4.noteOff();
  ampEnvelope4.noteOff();
  filterEnvelope5.noteOff();
  ampEnvelope5.noteOff();
  filterEnvelope6.noteOff();
  ampEnvelope6.noteOff();

  voices[0].voiceOn = false;
  voices[1].voiceOn = false;
  voices[2].voiceOn = false;
  voices[3].voiceOn = false;
  voices[4].voiceOn = false;
  voices[5].voiceOn = false;
}

int getVoiceNo(int note)
{
  voiceToReturn = -1;      //Initialise
  earliestTime = millis(); //Initialise to now
  if (note == -1)
  {
    //NoteOn() - Get the oldest free voice (recent voices may be still on release stage)
    for (int i = 0; i < NO_OF_VOICES; i++)
    {
      if (voices[i].voiceOn == false)
      {
        if (voices[i].timeOn < earliestTime)
        {
          earliestTime = voices[i].timeOn;
          voiceToReturn = i;
        }
      }
    }
    if (voiceToReturn == -1)
    {
      //No free voices, need to steal oldest sounding voice
      earliestTime = millis(); //Reinitialise
      for (int i = 0; i < NO_OF_VOICES; i++)
      {
        if (voices[i].timeOn < earliestTime)
        {
          earliestTime = voices[i].timeOn;
          voiceToReturn = i;
        }
      }
    }
    return voiceToReturn + 1;
  }
  else
  {
    //NoteOff() - Get voice number from note
    for (int i = 0; i < NO_OF_VOICES; i++)
    {
      if (voices[i].note == note && voices[i].voiceOn)
      {
        return i + 1;
      }
    }
  }
  //Shouldn't get here, return voice 1
  return 1;
}

void updateVoice1()
{
  if (oscWaveformA == WAVEFORM_SAWTOOTH_WT) waveformMod1a.arbitraryWaveform(sawtoothWavetable[(voices[0].note + oscPitchA) / 3 + 1], AWFREQ);
  if (oscWaveformB == WAVEFORM_SAWTOOTH_WT) waveformMod1b.arbitraryWaveform(sawtoothWavetable[(voices[0].note + oscPitchB) / 3 + 1], AWFREQ);
  if (oscWaveformA == WAVEFORM_SQUARE_WT) waveformMod1a.arbitraryWaveform(squareWavetable[(voices[0].note + oscPitchA) / 3 + 1], AWFREQ);
  if (oscWaveformB == WAVEFORM_SQUARE_WT) waveformMod1b.arbitraryWaveform(squareWavetable[(voices[0].note + oscPitchB) / 3 + 1], AWFREQ);

  waveformMod1a.frequency(NOTEFREQS[voices[0].note + oscPitchA]);
  if (unison == 1)
  {
    waveformMod1b.frequency(NOTEFREQS[voices[0].note + oscPitchB] * (detune + ((1 - detune) * 0.09)));
  }
  else
  {
    waveformMod1b.frequency(NOTEFREQS[voices[0].note + oscPitchB] * detune);
  }
}
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
void loop()
{
  myusb.Task();
  midi1.read(midiChannel);   //USB HOST MIDI Class Compliant
  usbMIDI.read(midiChannel); //USB Client MIDI
  MIDI.read(midiChannel);    //MIDI 5 Pin DIN

  checkMux();
  checkSwitches();
  checkEncoder();
  //CPUMonitor();
}

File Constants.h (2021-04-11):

const char* VERSION = "V1.29";
const static uint32_t PROGMEM FILTERFREQS256[256] = {20, 21, 22, 23, 24, 26, 27, 28, 29, 31, 32, 33, 34, 35, 36, 38, 39, 40, 41, 43, 44, 46, 47, 49, 50, 52, 53, 55, 57, 59, 61, 63, 65, 68, 70, 73, 76, 78, 81, 84, 87, 91, 94, 98, 102, 106, 110, 114, 119, 123, 128, 133, 138, 144, 149, 155, 161, 167, 174, 181, 187, 195, 202, 210, 218, 226, 234, 243, 252, 261, 271, 281, 291, 301, 312, 323, 334, 346, 358, 370, 383, 395, 409, 422, 436, 451, 465, 480, 496, 512, 528, 544, 561, 578, 596, 614, 633, 652, 671, 691, 711, 732, 753, 774, 796, 818, 841, 865, 888, 913, 937, 962, 988, 1014, 1041, 1068, 1096, 1124, 1152, 1182, 1211, 1242, 1272, 1304, 1335, 1368, 1401, 1434, 1468, 1503, 1538, 1574, 1610, 1647, 1684, 1722, 1761, 1800, 1840, 1881, 1922, 1964, 2006, 2049, 2093, 2137, 2182, 2227, 2274, 2320, 2368, 2416, 2465, 2515, 2565, 2616, 2668, 2720, 2773, 2827, 2881, 2936, 2992, 3049, 3106, 3164, 3223, 3283, 3343, 3404, 3466, 3529, 3592, 3656, 3721, 3787, 3853, 3921, 3989, 4058, 4127, 4198, 4269, 4341, 4414, 4488, 4563, 4638, 4715, 4792, 4870, 4949, 5029, 5109, 5191, 5273, 5357, 5441, 5526, 5612, 5699, 5787, 5876, 5965, 6056, 6147, 6240, 6333, 6427, 6523, 6619, 6716, 6814, 6913, 7013, 7114, 7216, 7319, 7424, 7529, 7635, 7742, 7850, 7959, 8069, 8180, 8292, 8405, 8519, 8634, 8751, 8868, 8986, 9106, 9226, 9348, 9471, 9594, 9719, 9845, 9972, 10100, 10230, 10360, 10491, 10624, 10758, 10893, 11029, 11166, 11304, 11443, 11584, 11726, 11869, 12000};
const float POWER[128] = {0, 0.00009, 0.0003, 0.0006, 0.001, 0.0016, 0.0022, 0.003, 0.004, 0.005, 0.0062, 0.0075, 0.0089, 0.0105, 0.0122, 0.014, 0.016, 0.018, 0.02, 0.022, 0.025, 0.027, 0.03, 0.033, 0.036, 0.039, 0.042, 0.045, 0.049, 0.052, 0.056, 0.06, 0.063, 0.068, 0.072, 0.076, 0.08, 0.085, 0.09, 0.094, 0.099, 0.104, 0.109, 0.115, 0.12, 0.126, 0.131, 0.137, 0.143, 0.149, 0.155, 0.161, 0.168, 0.174, 0.181, 0.188, 0.194, 0.201, 0.209, 0.216, 0.223, 0.231, 0.238, 0.246, 0.254, 0.262, 0.27, 0.278, 0.287, 0.295, 0.304, 0.313, 0.321, 0.33, 0.34, 0.349, 0.358, 0.368, 0.377, 0.387, 0.397, 0.407, 0.417, 0.427, 0.437, 0.448, 0.459, 0.469, 0.48, 0.491, 0.502, 0.513, 0.525, 0.536, 0.548, 0.56, 0.571, 0.583, 0.595, 0.608, 0.62, 0.632, 0.645, 0.658, 0.671, 0.684, 0.697, 0.71, 0.723, 0.737, 0.75, 0.764, 0.778, 0.792, 0.806, 0.82, 0.834, 0.849, 0.863, 0.878, 0.893, 0.908, 0.923, 0.938, 0.953, 0.969, 0.984, 1};
const float NOTEFREQS[128] = {8.176, 8.662, 9.177, 9.723, 10.301, 10.913, 11.562, 12.25, 12.978, 13.75, 14.568, 15.434, 16.352, 17.324, 18.354, 19.445, 20.602, 21.827, 23.125, 24.5, 25.957, 27.5, 29.135, 30.868, 32.703, 34.648, 36.708, 38.891, 41.203, 43.654, 46.249, 48.999, 51.913, 55, 58.27, 61.735, 65.406, 69.296, 73.416, 77.782, 82.407, 87.307, 92.499, 97.999, 103.826, 110, 116.541, 123.471, 130.813, 138.591, 146.832, 155.563, 164.814, 174.614, 184.997, 195.998, 207.652, 220, 233.082, 246.942, 261.626, 277.183, 293.665, 311.127, 329.628, 349.228, 369.994, 391.995, 415.305, 440, 466.164, 493.883, 523.251, 554.365, 587.33, 622.254, 659.255, 698.456, 739.989, 783.991, 830.609, 880, 932.328, 987.767, 1046.502, 1108.731, 1174.659, 1244.508, 1318.51, 1396.913, 1479.978, 1567.982, 1661.219, 1760, 1864.655, 1975.533, 2093.005, 2217.461, 2349.318, 2489.016, 2637.02, 2793.826, 2959.955, 3135.963, 3322.438, 3520, 3729.31, 3951.066, 4186.009, 4434.922, 4698.636, 4978.032, 5274.041, 5587.652, 5919.911, 6271.927, 6644.875, 7040, 7458.62, 7902.133, 8372.018, 8869.844, 9397.273, 9956.063, 10548.08, 11175.3, 11839.82, 12543.85};
const float ENVTIMES[128] = {1, 2, 4, 6, 9, 14, 20, 26, 33, 41, 49, 58, 67, 78, 89, 99, 111, 124, 136, 150, 164, 178, 192, 209, 224, 241, 258, 276, 295, 314, 333, 353, 374, 395, 418, 440, 464, 489, 513, 539, 565, 592, 621, 650, 680, 710, 742, 774, 808, 843, 878, 915, 952, 991, 1031, 1073, 1114, 1158, 1202, 1250, 1297, 1346, 1396, 1448, 1502, 1558, 1614, 1676, 1735, 1794, 1864, 1923, 1994, 2065, 2136, 2207, 2289, 2360, 2443, 2525, 2620, 2702, 2797, 2891, 2985, 3092, 3186, 3292, 3410, 3516, 3634, 3752, 3882, 4012, 4142, 4272, 4413, 4567, 4708, 4862, 5027, 5180, 5357, 5522, 5699, 5888, 6077, 6278, 6478, 6691, 6903, 7127, 7351, 7587, 7835, 8083, 8343, 8614, 8885, 9169, 9464, 9770, 10077, 10408, 10738, 11080, 11434, 11700};
const float LFOTEMPO[128] = {8, 8, 8, 8, 8, 8, 8, 8, 6, 6, 6, 6, 6, 6, 6, 6, 4, 4, 4, 4, 4, 4, 4, 4, 3, 3, 3, 3, 3, 3, 3, 3, 2, 2, 2, 2, 2, 2, 2, 2, 1.5, 1.5, 1.5, 1.5, 1.5, 1.5, 1.5, 1.5, 1, 1, 1, 1, 1, 1, 1, 1, 0.75, 0.75, 0.75, 0.75, 0.75, 0.75, 0.75, 0.75, 0.5, 0.5, 0.5, 0.5, 0.5, 0.5, 0.5, 0.5, 0.333, 0.333, 0.333, 0.333, 0.333, 0.333, 0.333, 0.333, 0.25, 0.25, 0.25, 0.25, 0.25, 0.25, 0.25, 0.25, 0.167, 0.167, 0.167, 0.167, 0.167, 0.167, 0.167, 0.167, 0.125, 0.125, 0.125, 0.125, 0.125, 0.125, 0.125, 0.125, 0.083, 0.083, 0.083, 0.083, 0.083, 0.083, 0.083, 0.083, 0.063, 0.063, 0.063, 0.063, 0.063, 0.063, 0.063, 0.063, 0.047, 0.047, 0.047, 0.047, 0.047, 0.047, 0.047, 0.047};
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

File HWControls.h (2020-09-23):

// This optional setting causes Encoder to use more optimized code,
// It must be defined before Encoder.h is included.
#define ENCODER_OPTIMIZE_INTERRUPTS
#include <Encoder.h>
#include <Bounce.h>
#include <ADC.h>
#include <ADC_util.h>

ADC *adc = new ADC();

//Teensy 3.6 - Mux Pins
#define MUX_0 28
#define MUX_1 27
#define MUX_2 26
#define MUX_3 25
#define MUX1_S 38
#define MUX2_S A22
//Mux 1 Connections
#define MUX1_noiseLevel 0
#define MUX1_pitchLfoRate 1
#define MUX1_pitchLfoWaveform 2
#define MUX1_pitchLfoAmount 3
#define MUX1_detune 4
#define MUX1_oscMix 5
#define MUX1_filterAttack 6
#define MUX1_filterDecay 7
#define MUX1_pwmAmountA 8
#define MUX1_waveformA 9
#define MUX1_pitchA 10
#define MUX1_pwmAmountB 11
#define MUX1_waveformB 12
#define MUX1_pitchB 13
#define MUX1_pwmRate 14
#define MUX1_pitchEnv 15
//Mux 2 Connections
#define MUX2_release 0
#define MUX2_sustain 1
#define MUX2_decay 2
#define MUX2_attack 3
#define MUX2_filterLFOAmount 4
#define MUX2_FXMix 5
#define MUX2_FXAmount 6
#define MUX2_glide 7
#define MUX2_filterEnv 8
#define MUX2_filterRelease 9
#define MUX2_filterSustain 10
#define MUX2_filterType 11
#define MUX2_resonance 12
#define MUX2_cutoff 13
#define MUX2_filterLFORate 14
#define MUX2_filterLFOWaveform 15

//Teensy 3.6 Pins
#define OSC_FX_SW 39
#define FILTER_LFO_RETRIG_SW 30
#define UNISON_SW 36
#define TEMPO_SW 16
#define RECALL_SW 17
#define SAVE_SW 24
#define SETTINGS_SW 12
#define BACK_SW 10
#define VOLUME_POT A14

#define ENCODER_PINA 4
#define ENCODER_PINB 5

#define RETRIG_LED 34
#define TEMPO_LED 35
#define UNISON_LED 37
#define OSC_FX_LED 14 

#define MUXCHANNELS 16
#define QUANTISE_FACTOR 15//Window of noise before change detected in controls. 15 is 4 bits

#define DEBOUNCE 30

static byte muxInput = 0;
static int mux1ValuesPrev[MUXCHANNELS] = {};
static int mux2ValuesPrev[MUXCHANNELS] = {};

static int mux1Read = 0;
static int mux2Read = 0;
static int volumeRead = 0;
static int volumePrevious = 0;
static long encPrevious = 0;

//These are pushbuttons and require debouncing
Bounce oscFXSwitch = Bounce(OSC_FX_SW, DEBOUNCE);
Bounce filterLFORetrigSwitch = Bounce(FILTER_LFO_RETRIG_SW, DEBOUNCE);
Bounce unisonSwitch = Bounce(UNISON_SW, DEBOUNCE);
Bounce tempoSwitch = Bounce(TEMPO_SW, DEBOUNCE);

Bounce recallButton = Bounce(RECALL_SW, DEBOUNCE); //On encoder
boolean recall = true; //Hack for recall button
Bounce saveButton = Bounce(SAVE_SW, DEBOUNCE);
boolean del = true; //Hack for save button
Bounce settingsButton = Bounce(SETTINGS_SW, DEBOUNCE);
boolean reini = true; //Hack for settings button
Bounce backButton = Bounce(BACK_SW, DEBOUNCE);
boolean panic = true; //Hack for back button
Encoder encoder(ENCODER_PINB, ENCODER_PINA);//This often needs the pins swapping depending on the encoder

void setupHardware()
{
  //Volume Pot is on ADC0
  adc->adc0->setAveraging(16); // set number of averages 0, 4, 8, 16 or 32.
  adc->adc0->setResolution(12); // set bits of resolution  8, 10, 12 or 16 bits.
  adc->adc0->setConversionSpeed(ADC_CONVERSION_SPEED::VERY_LOW_SPEED); // change the conversion speed
  adc->adc0->setSamplingSpeed(ADC_SAMPLING_SPEED::MED_SPEED); // change the sampling speed

  //MUXs on ADC1
  adc->adc1->setAveraging(16); // set number of averages 0, 4, 8, 16 or 32.
  adc->adc1->setResolution(12); // set bits of resolution  8, 10, 12 or 16 bits.
  adc->adc1->setConversionSpeed(ADC_CONVERSION_SPEED::VERY_LOW_SPEED); // change the conversion speed
  adc->adc1->setSamplingSpeed(ADC_SAMPLING_SPEED::MED_SPEED); // change the sampling speed

  //Mux address pins
  pinMode(MUX_0, OUTPUT);
  pinMode(MUX_1, OUTPUT);
  pinMode(MUX_2, OUTPUT);
  pinMode(MUX_3, OUTPUT);

  //Switches
  pinMode(OSC_FX_SW, INPUT_PULLUP);
  pinMode(FILTER_LFO_RETRIG_SW, INPUT_PULLUP);
  pinMode(UNISON_SW, INPUT_PULLUP);
  pinMode(TEMPO_SW, INPUT_PULLUP);
  pinMode(RECALL_SW, INPUT_PULLUP); //On encoder
  pinMode(SAVE_SW, INPUT_PULLUP);
  pinMode(SETTINGS_SW, INPUT_PULLUP);
  pinMode(BACK_SW, INPUT_PULLUP);

  //LEDs
  pinMode(RETRIG_LED, OUTPUT);
  pinMode(TEMPO_LED, OUTPUT);
  pinMode(UNISON_LED, OUTPUT);
  pinMode(OSC_FX_LED, OUTPUT);
}

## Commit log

2019-12-30 Removed 'AudioNoInterrupts' that caused... interrupts and occasionally noise.
    [Constants.h, ST7735Display.h, TSynth.ino]
2020-03-09 Fix ISO C++ forbids converting a string constant to 'char*'
    [ST7735Display.h]
2020-03-17 PCB REV 1.1
2020-04-28 TSynth V1.1 for Rev 1.1 PCB
2020-05-19 Updated to Teensyduino 1.52
2020-05-22 Compiled 180MHz Fastest with LTO
    Overclocking produces problems reading encoder smoothly.
2020-06-03 Filter octave changes
2020-07-08 Updated for Teensyduino 1.53
2020-07-28 Improved - frequency changes while voices sounding, uses digitalWriteFast, usbAudio object created earlier, detune goes up to 5%
    Moving Pitch controls for both oscillators and detune will now have an effect on the sound even if notes aren't being held but still sounding.
    digitalWrite has been replaced with digitalWriteFast - no noticeable effect but any increase is speed is acceptable.
    usbAudio was moved to be created earlier, this removed some digital noise when developing T4.1, so we'll try here too.
    Detune maximum increased from 4% to 5% - why not?
2020-07-28 Improved - frequency changes while voices sounding, uses digitalWrite… …Fast, usbAudio object created earlier, detune goes up to 5%
    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
    [Constants.h, ST7735Display.h, TSynth.ino]
2020-08-04 Removing not needed folder for "Modified Libraries". Fixing the docs by removing the hint for "Modified Libraries". Adding hint for installing needed external library "Adafruit_GFX".
    [TSynth.ino]
2020-08-07 Update TSynth.ino
    Put replacement file headers at top
    [TSynth.ino]
2020-08-07 V1.15 - Improved handling of local versions of overridden library files and prevent control reading altering first patch loaded
    [Constants.h, TSynth.ino, synth_waveform.h]
2020-08-18 Velocity sensitivity added and small fix to PWM source changing.
2020-08-18 Added velocity sensitivity.
2020-08-26 Fix glide and change icon for 'pick-up'.
    [Constants.h, ST7735Display.h, ST7735_t3.h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]
2020-09-10 Filter response improvements.
2020-09-10 Improved filter response.
2020-09-13 Add files via upload
    Adapter Board to adapt a T4.1 to fit on the Rev 1.1 T3.6-based board.
2020-09-17 Improve ADC reads. Increase AudioMemory slightly.
2020-09-17 Improve ADC reads. Increase AudioMemory.
2020-10-18 V1.28 - Mod wheel level adds to osc LFO level.
